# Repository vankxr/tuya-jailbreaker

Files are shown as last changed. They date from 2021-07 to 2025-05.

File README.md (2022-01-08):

# tuya-jailbreaker
This small module aims to replace the original Wi-Fi module present in Tuya/Elivco smart plugs. The pin connections were reverse engineered from the base PCB traces, and the pad dimensions/spacing was measured from the original module.

## Pictures
The original module in blue, the ESP8285 module in green.

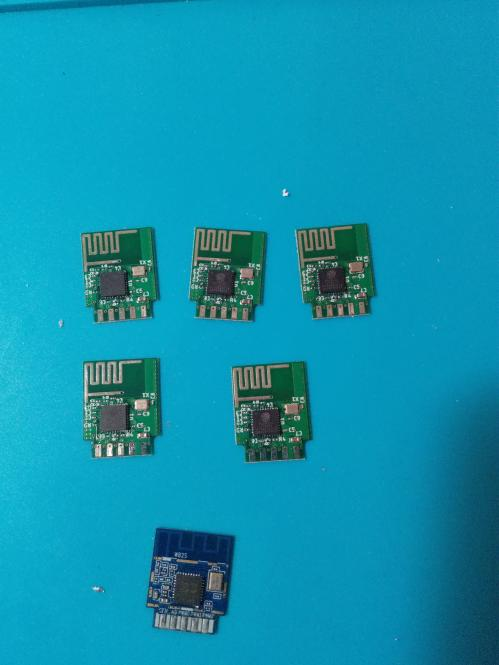
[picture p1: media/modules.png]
modules

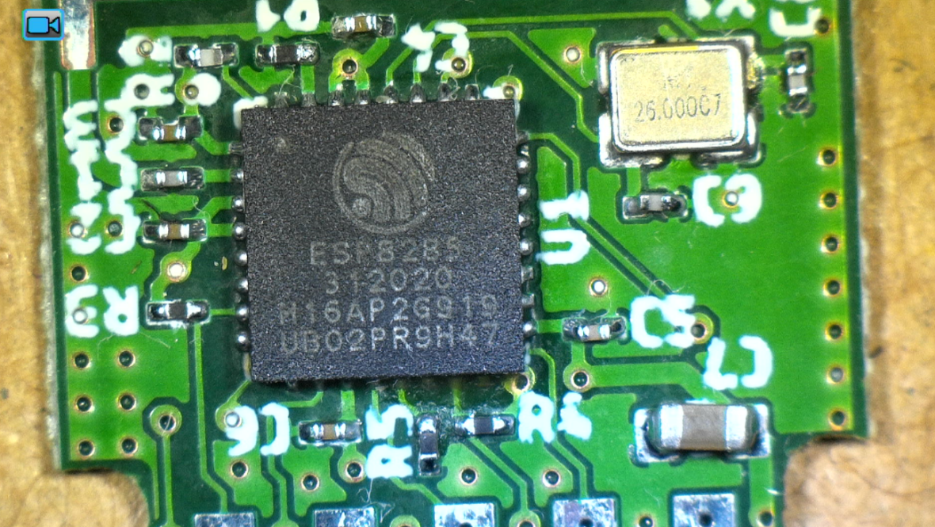
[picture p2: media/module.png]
module


## Hardware
These modules are kind of impossible to disassemble without leaving some marks behind. Fortunately, after almost destroying the case of the first one I disassembled, I was able to figure out how they are put together and further teardowns were much easier.
Basically the trick is to drill three very small holes, and prying the two parts apart with a small screwdriver inserted into the holes. One hole for each side of the case, the side that has the push-button should not have a hole.
After hearing a click sound, the two parts can easily be separated, taking care not to rip apart the Earth connection.

Re-assembly is then performed by attaching everything and filling the previously mentioned holes with hot glue.

TODO: Add pictures

## Software
The jailbreaker was flashed with [Tasmota](https://tasmota.github.io/docs/), and it was configured with the correct pinout for the Energy Metering IC that is present in the base PCB.

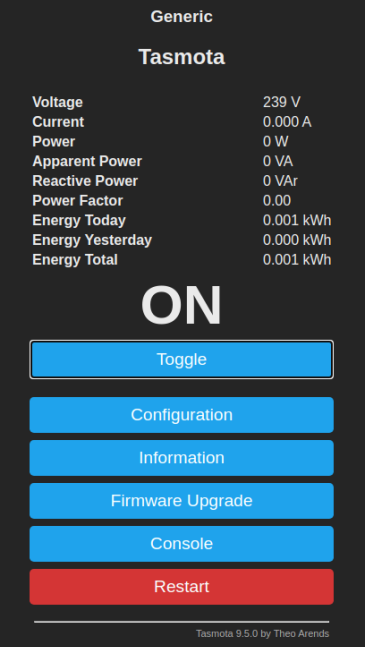
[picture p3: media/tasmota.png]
tasmota


## Tasmota configuration
The first module I ordered back in June 2021 used the BL0937 energy metering IC, so naturally I designed this PCB taking this insto account after figuring out the pinout.
Later though, I ordered more modules, and realised they were slightly different. Modules ordered in November 2021 came with the BL0942 energy metering IC, which seems to be better since it does not require calibration. Even though I only figured this out after removing the original module and installing a jailbreak module, I was able to figure out which pins are connected to the energy metering IC and fortunately everything worked after configuring them correctly. Below are screenshots of Tasmota configuration for both versions of the base PCB.
### v1 (version with BL0937)
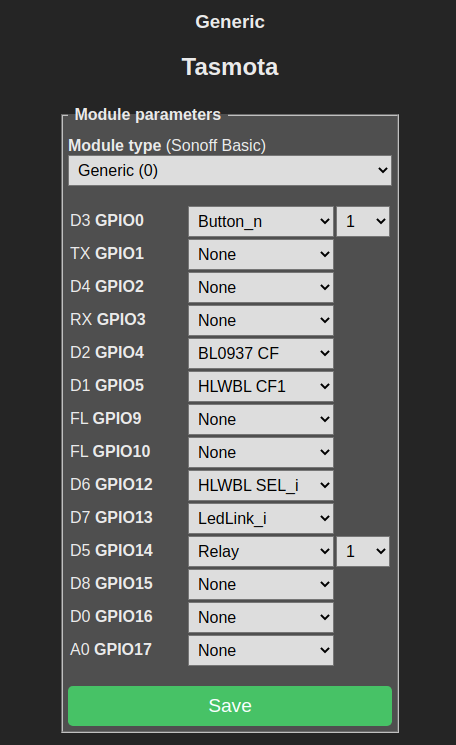
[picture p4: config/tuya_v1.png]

### v2 (version with BL0942)
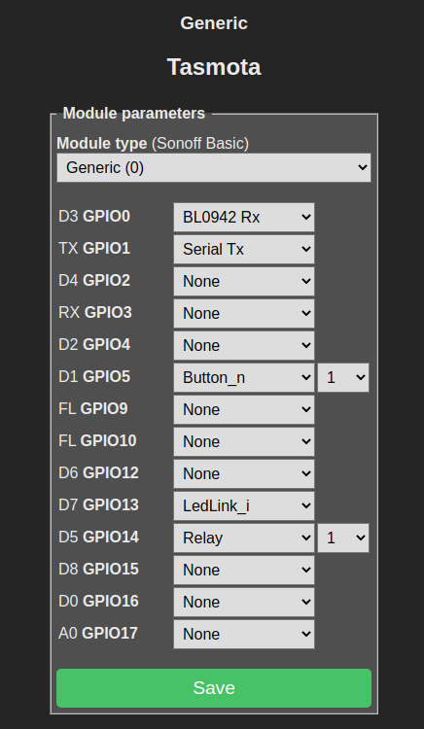
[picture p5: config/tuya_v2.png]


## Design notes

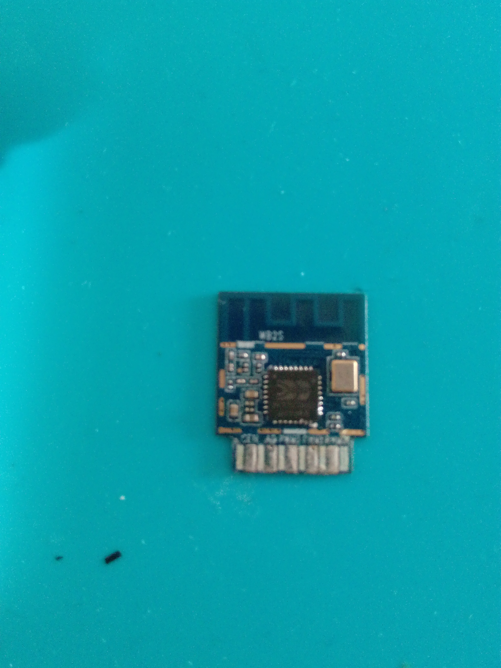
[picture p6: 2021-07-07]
media/plug5.jpg

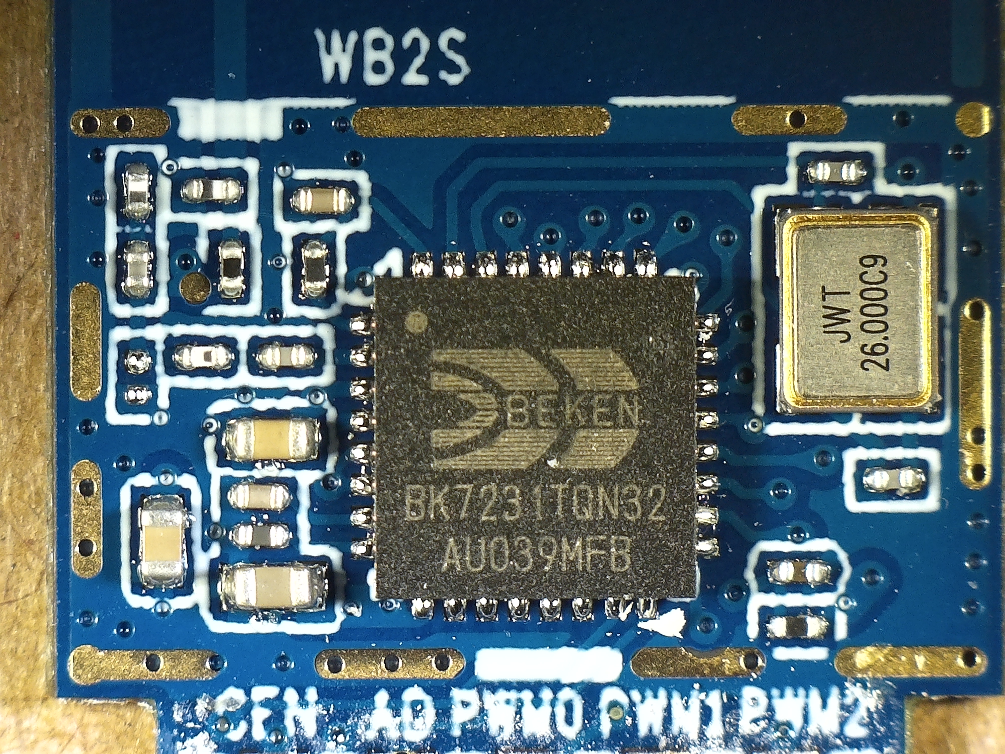
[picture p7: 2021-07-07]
media/plug1.jpg

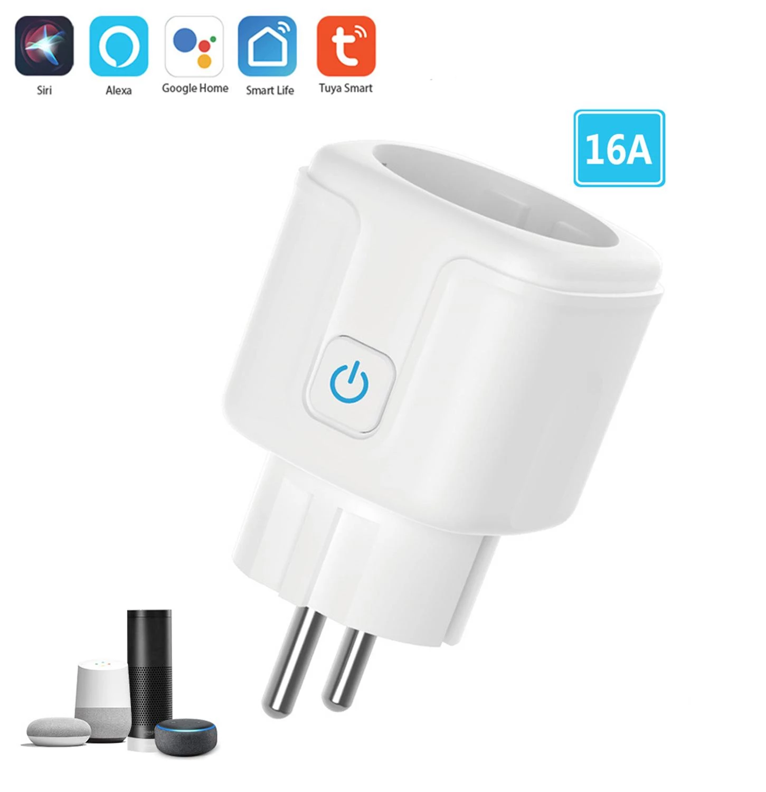
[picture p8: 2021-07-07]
media/plug.png

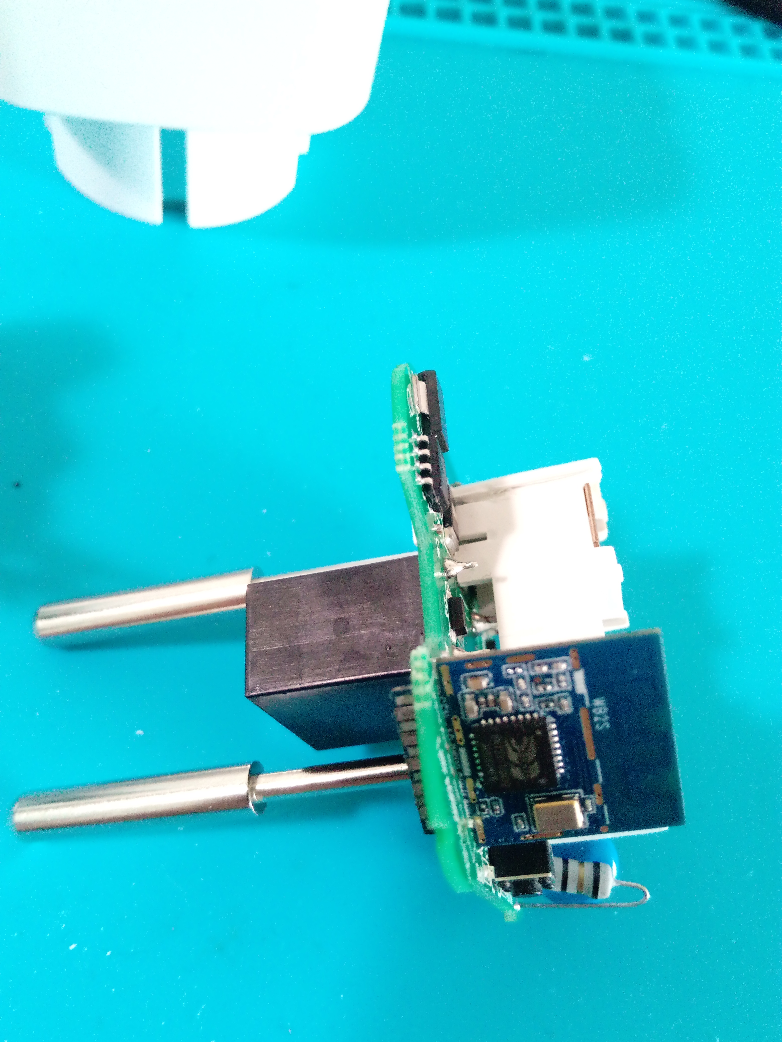
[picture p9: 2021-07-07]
media/plug3.jpg

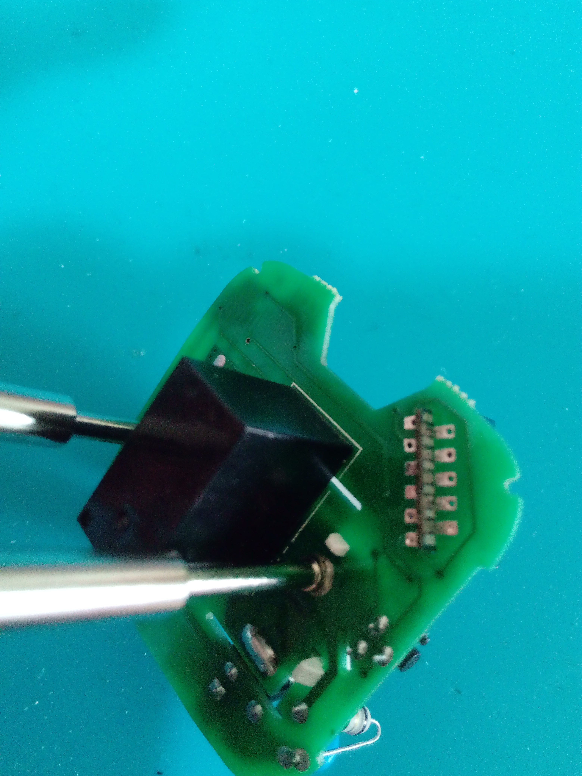
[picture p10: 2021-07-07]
media/plug4.jpg

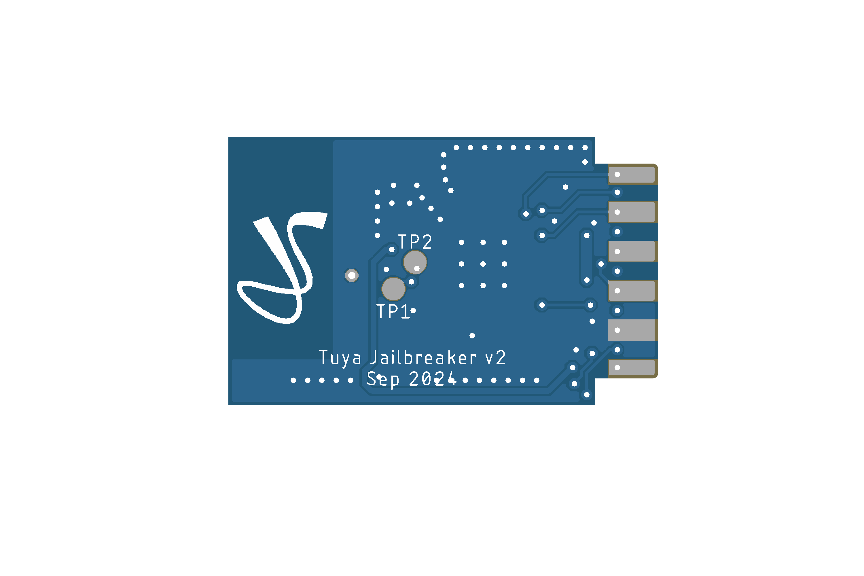
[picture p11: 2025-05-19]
pcb/tuya-jailbeaker-bot.png

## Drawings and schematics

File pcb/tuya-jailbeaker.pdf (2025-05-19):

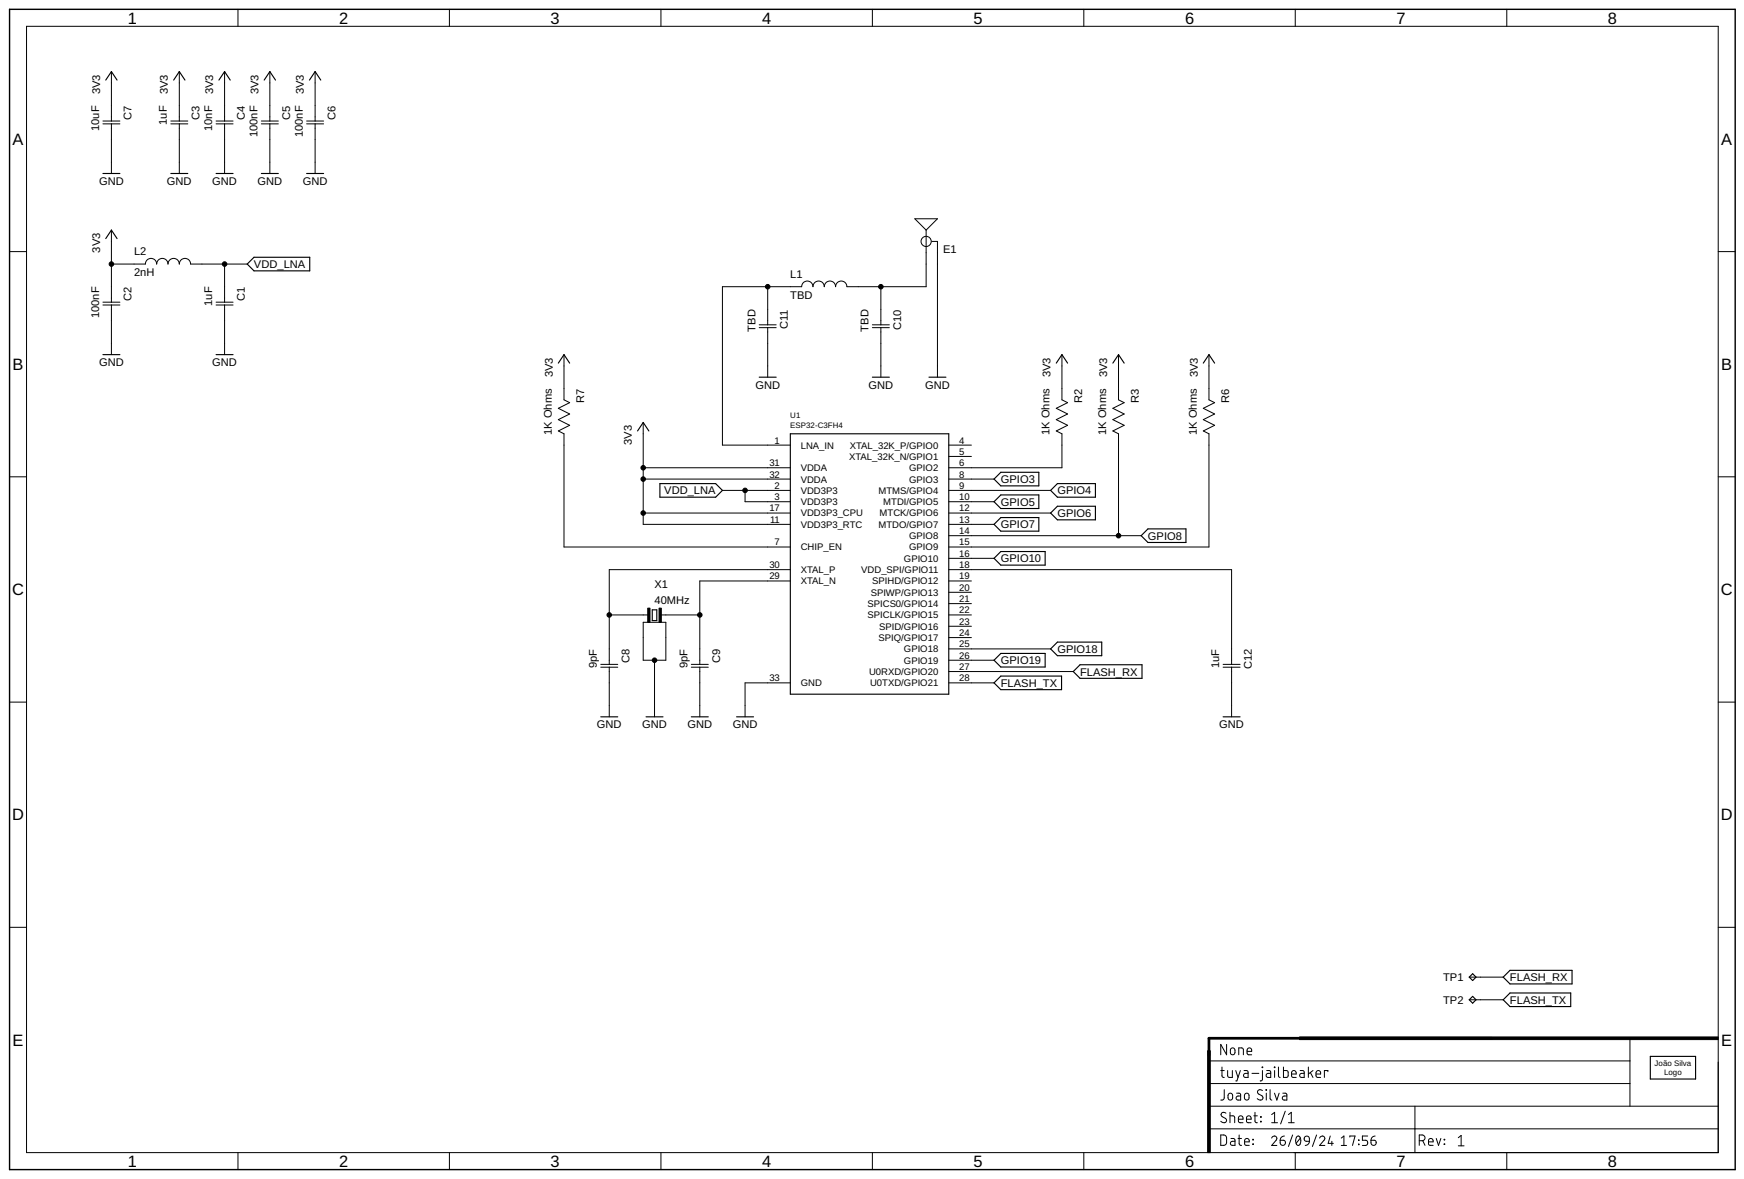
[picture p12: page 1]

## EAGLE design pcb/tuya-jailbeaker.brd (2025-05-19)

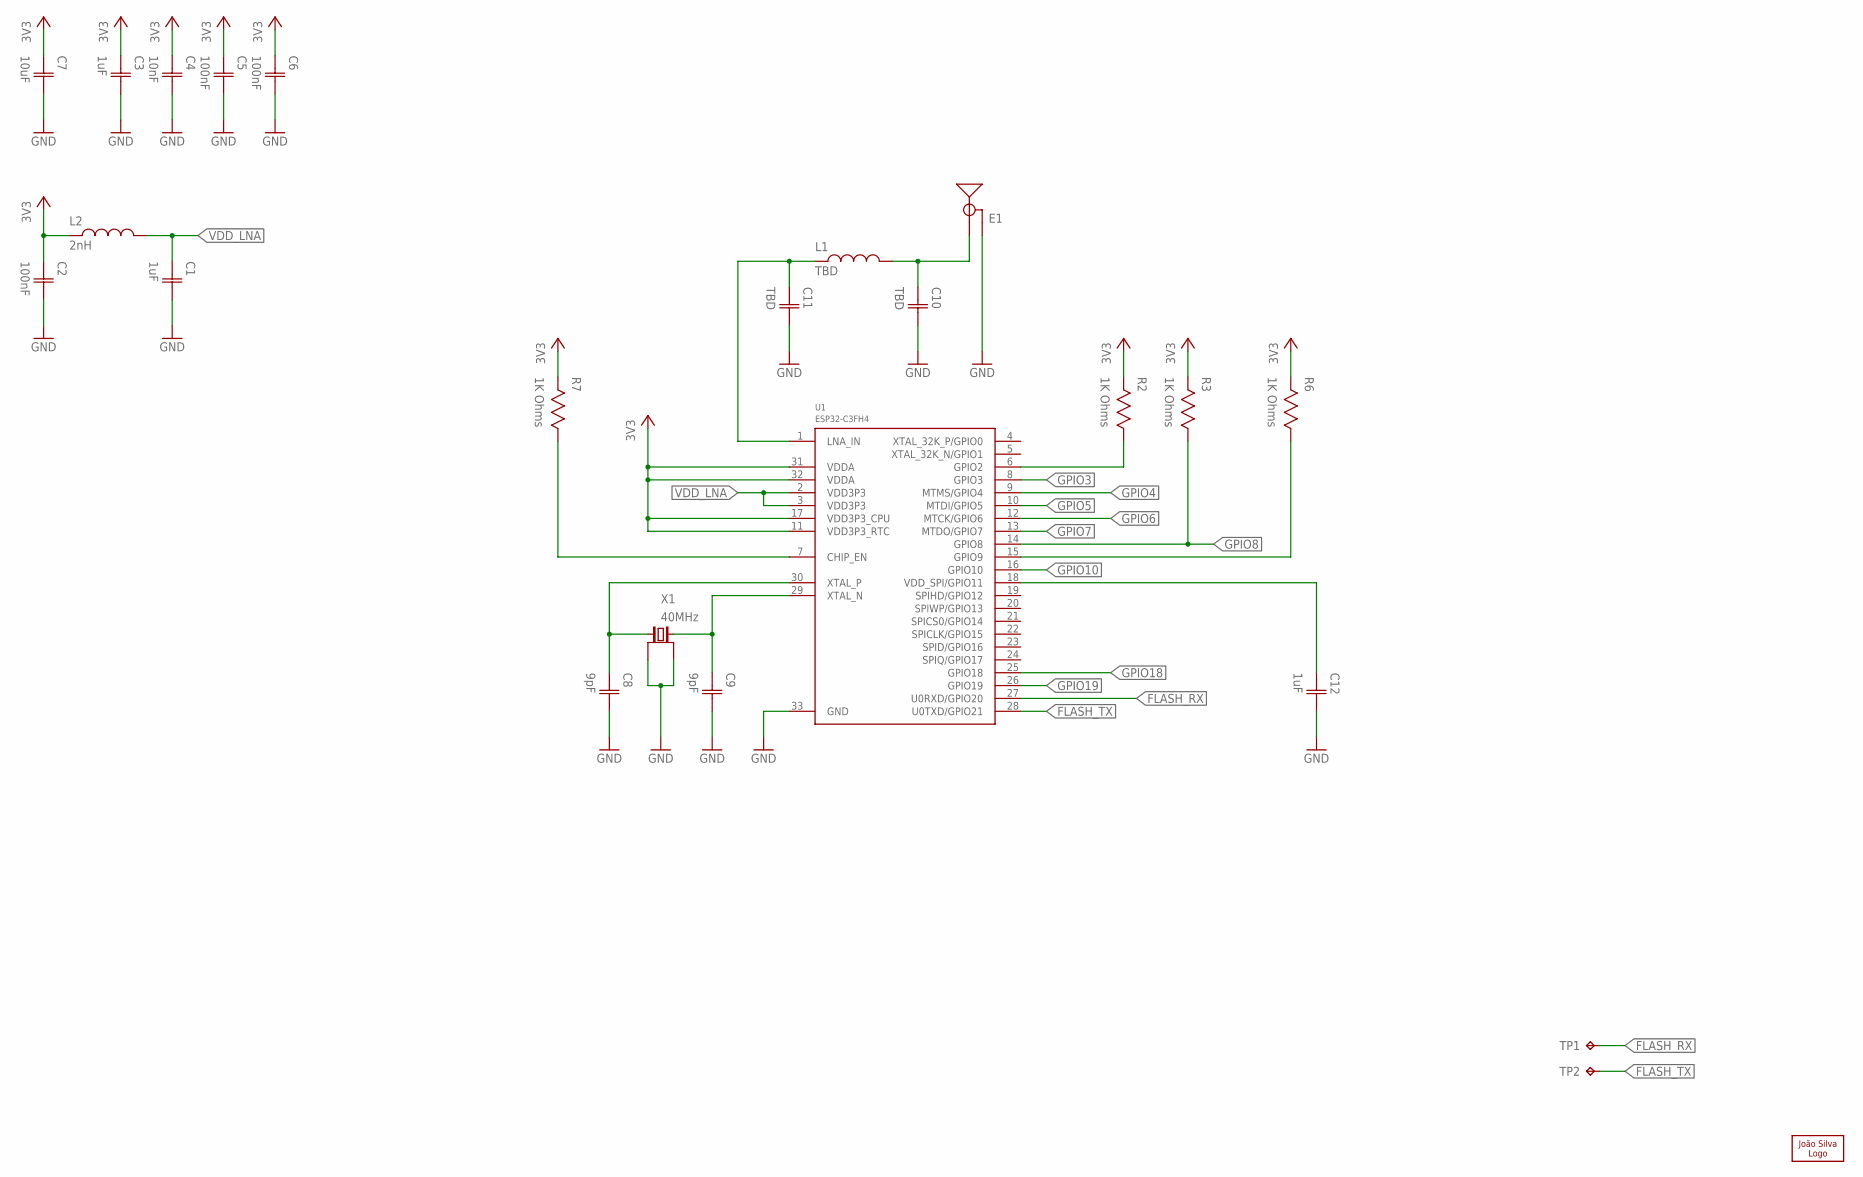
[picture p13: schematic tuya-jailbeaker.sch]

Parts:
C1, C3, C12: 1uF; CAP0402
C2, C5, C6: 100nF; CAP0402
C4: 10nF; CAP0402
C7: 10uF; CAP0603
C8, C9: 9pF; CAP0402
C10, C11: TBD; CAP0402
E1: 2.4GHZ; OLIMEX_ANT_ESP8266_ANT
L1: TBD; IND0402
L2: 2nH; IND0402
LOGO1: JS-5MM; JS_5MM
R2, R3, R6, R7: 1K Ohms; RES0402
TP1, TP2: TESTPOINT-1.27MM; PAD1.27MM
U1: ESP32-C3FH4; QFN32
X1: 40MHz; 4-SMD-2520

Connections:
3V3: C2.1 (C1), C3.1 (C1), C4.1 (C1), C5.1 (C1), C6.1 (C1), C7.1 (C1), L2.1, R2.2, R3.2, R6.2, R7.2, U1.11 (VDD3P3_RTC), U1.17 (VDD3P3_CPU), U1.31 (VDDA), U1.32 (VDDA)
ANT: C10.1 (C1), E1.ANT (SIGNAL), L1.2
CEN: R7.1, U1.7 (CHIP_EN)
FLASH_RX: TP1.TP, U1.27 (U0RXD/GPIO20)
FLASH_TX: TP2.TP, U1.28 (U0TXD/GPIO21)
GND: C1.2 (C2), C2.2 (C2), C3.2 (C2), C4.2 (C2), C5.2 (C2), C6.2 (C2), C7.2 (C2), C8.2 (C2), C9.2 (C2), C10.2 (C2), C11.2 (C2), C12.2 (C2), E1.GND, U1.33 (GND), X1.2 (GND), X1.4 (GND)
GPIO2: R2.1, U1.6 (GPIO2)
GPIO3: U1.8 (GPIO3)
GPIO4: U1.9 (MTMS/GPIO4)
GPIO5: U1.10 (MTDI/GPIO5)
GPIO6: U1.12 (MTCK/GPIO6)
GPIO7: U1.13 (MTDO/GPIO7)
GPIO8: R3.1, U1.14 (GPIO8)
GPIO9: R6.1, U1.15 (GPIO9)
GPIO10: U1.16 (GPIO10)
GPIO18: U1.25 (GPIO18)
GPIO19: U1.26 (GPIO19)
LNA_IN: C11.1 (C1), L1.1, U1.1 (LNA_IN)
VDD_LNA: C1.1 (C1), L2.2, U1.2 (VDD3P3), U1.3 (VDD3P3)
VDD_SPI: C12.1 (C1), U1.18 (VDD_SPI/GPIO11)
XTALN: C9.1 (C1), U1.29 (XTAL_N), X1.1 (2)
XTALP: C8.1 (C1), U1.30 (XTAL_P), X1.3 (1)

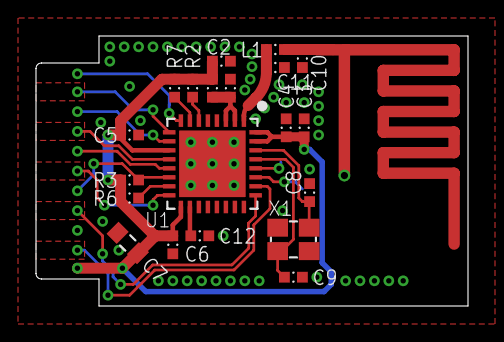
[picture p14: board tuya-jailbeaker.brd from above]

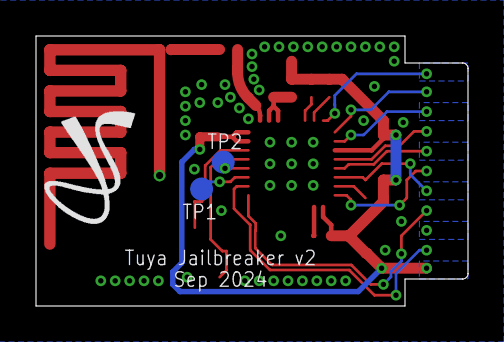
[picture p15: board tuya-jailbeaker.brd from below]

Board: 2 copper layers, 24.0 x 15.0 mm, 24 parts (3 on the bottom side), 14 nets.

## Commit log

2021-06-03 Add logo Generate schematic PDF
    [BOM_tuya-jailbeaker.csv, tuya-jailbeaker.brd, tuya-jailbeaker.sch]
2025-05-19 Update to ESP32-C3
    [BOM_tuya-jailbeaker.csv, tuya-jailbeaker.brd, tuya-jailbeaker.sch]
